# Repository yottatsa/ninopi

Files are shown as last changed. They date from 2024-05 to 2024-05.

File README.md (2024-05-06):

# ninopi

NinoTNC to Raspberry Pi integration board
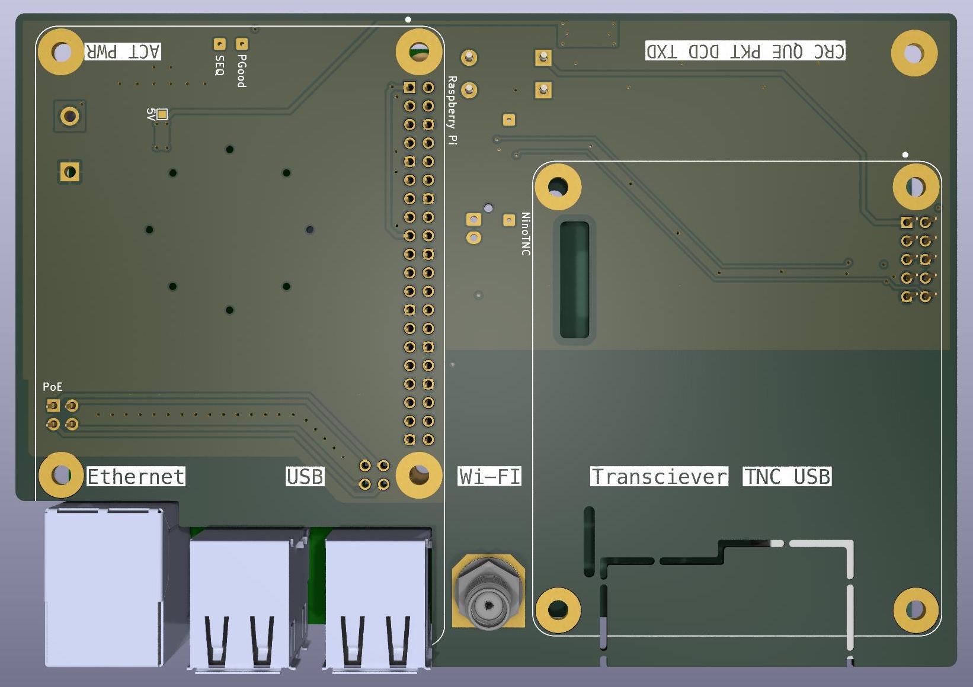
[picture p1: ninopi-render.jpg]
Card


[NinoTNC](https://tarpn.net/t/nino-tnc/nino-tnc.html) is 300-9600 baud multi-mode packet radio KISS TNC by [Nino Carrillo](https://github.com/ninocarrillo). This board bypassed provided USB-serial interface and uses rpi internal one.

This board also provides with [Recon 12V DC-DC converter](https://www.recom-power.com/pdf/Innoline/RPM-6.0.pdf) to power the rig from the same power rail, RPi and PoE headers pass-thru, Wi-Fi antenna mount, and simple fan PWM controller.

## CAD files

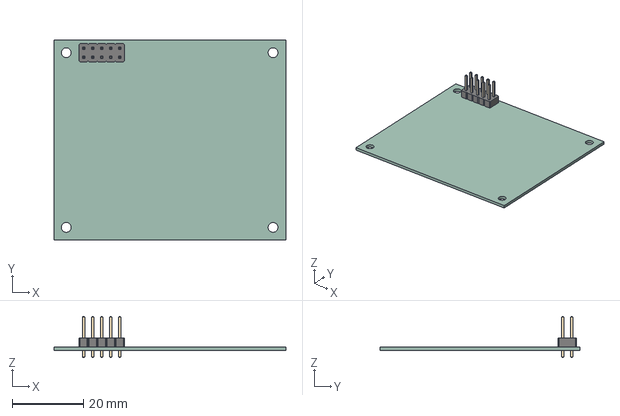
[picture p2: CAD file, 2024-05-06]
ninotnc.step
65.1 x 56.1 x 11.5 mm
_autosave-ninotnc PCB

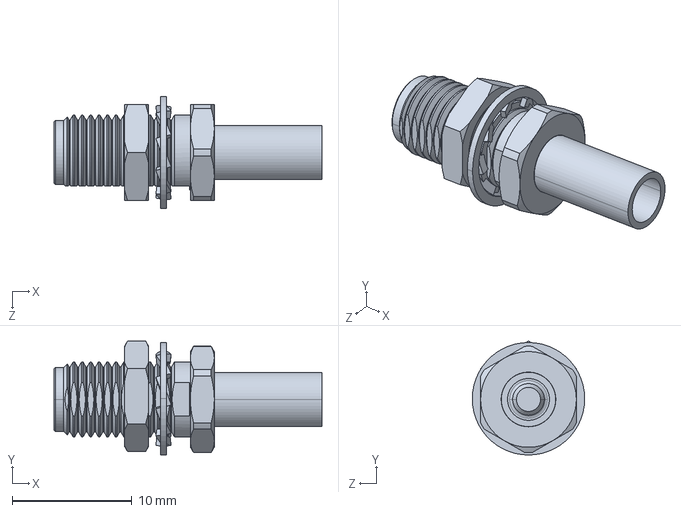
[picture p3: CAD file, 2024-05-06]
RASPBERRY_PI_3_MODEL_B_/7587.stp
22.4 x 9.52 x 9.40 mm

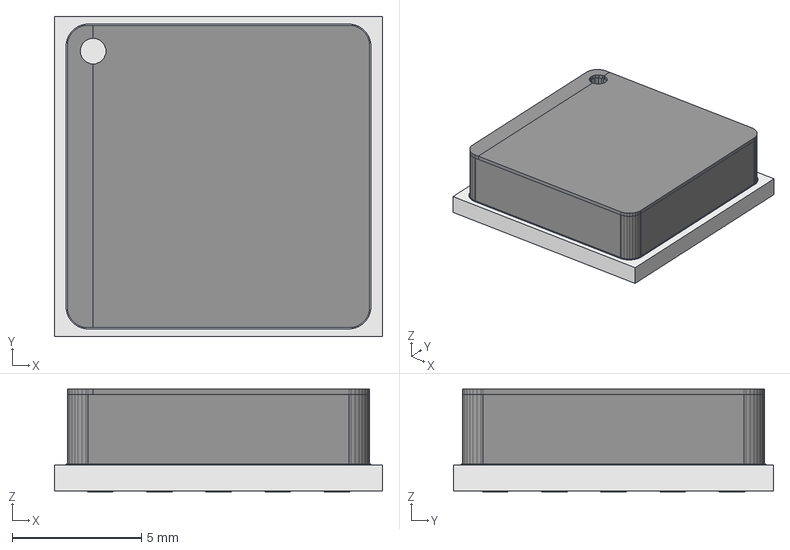
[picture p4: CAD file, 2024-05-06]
RPM60.stp
12.7 x 12.4 x 3.97 mm
Extruded.step x 2
Extruded-0.step x 2
Extruded-1.step x 2
Extruded-2.step x 2
Extruded-3.step x 2
Extruded-4.step x 2
Extruded-5.step003 x 4
Extruded-6.step003 x 4
RPM_RBB_PCB028
RPM_RBB_PCB029
RPM_RBB_PCB030
RPM_RBB_PCB031
RPM_RBB_PCB032
RPM_RBB_PCB033
RPM_RBB_PCB034
RPM_RBB_PCB035
RPM_RBB_PCB036
RPM_RBB_PCB037
RPM_RBB_PCB038
RPM_RBB_PCB039
RPM_RBB_PCB040
RPM_RBB_PCB041
RPM_RBB_PCB042
RPM_RBB_PCB043
RPM_RBB_PCB044
RPM_RBB_PCB045
RPM_RBB_PCB046
RPM_RBB_PCB047
RPM_RBB_PCB048
RPM_RBB_PCB049
RPM_RBB_PCB050
RPM_RBB_PCB051
RPM_RBB_PCB052
RPM_RBB_PCB053
RPM_RBB_PCB054
RPM_RBB_PCB
RPM_RBB_PCB001
RPM_RBB_PCB002
RPM_RBB_PCB003
RPM_RBB_PCB004
RPM_RBB_PCB005
RPM_RBB_PCB006
RPM_RBB_PCB007
RPM_RBB_PCB008
RPM_RBB_PCB009
RPM_RBB_PCB010
RPM_RBB_PCB011
RPM_RBB_PCB012
RPM_RBB_PCB013
RPM_RBB_PCB014
RPM_RBB_PCB015
RPM_RBB_PCB016
RPM_RBB_PCB017
RPM_RBB_PCB018
RPM_RBB_PCB019
RPM_RBB_PCB020
RPM_RBB_PCB021
RPM_RBB_PCB022
RPM_RBB_PCB023
RPM_RBB_PCB024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

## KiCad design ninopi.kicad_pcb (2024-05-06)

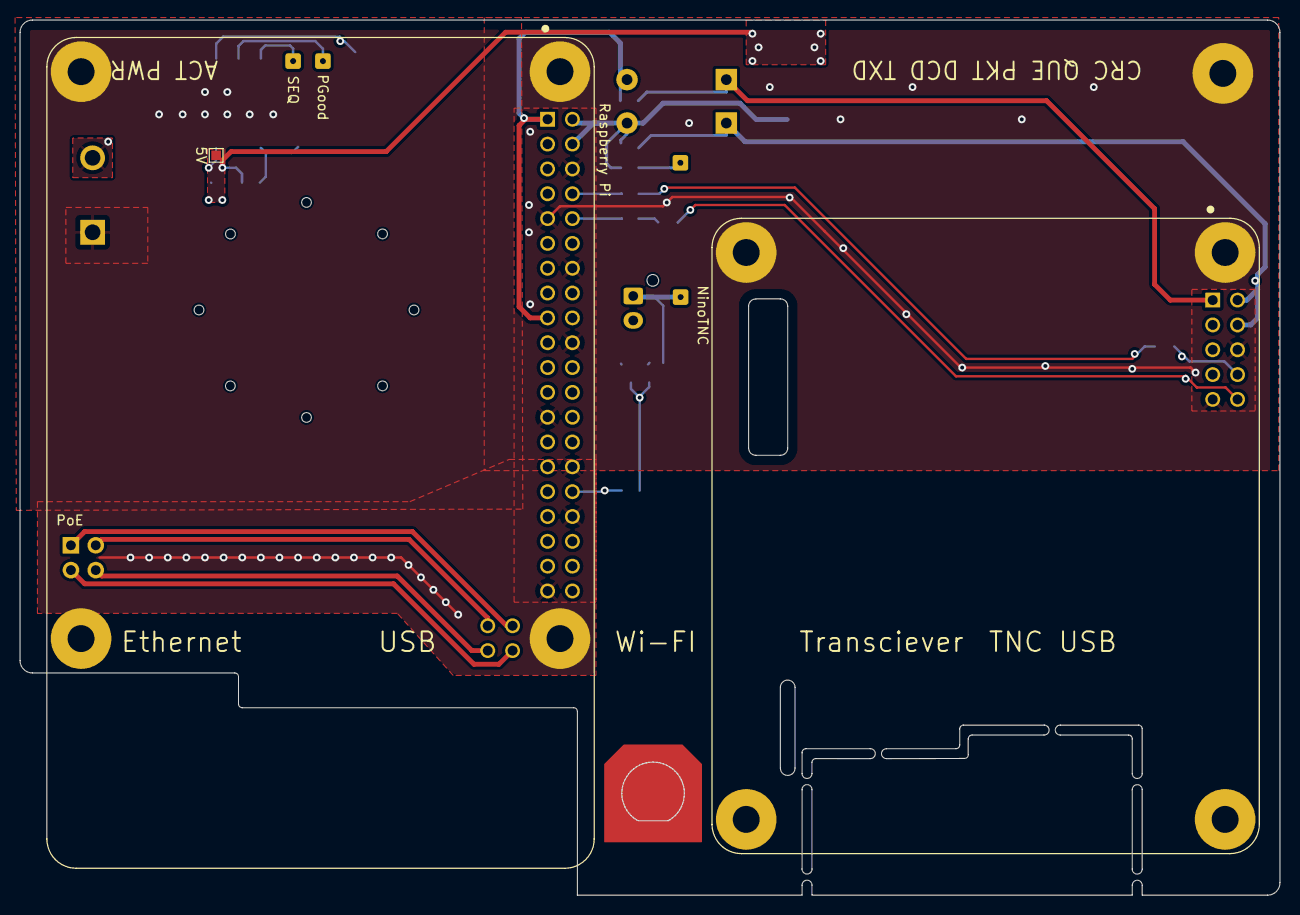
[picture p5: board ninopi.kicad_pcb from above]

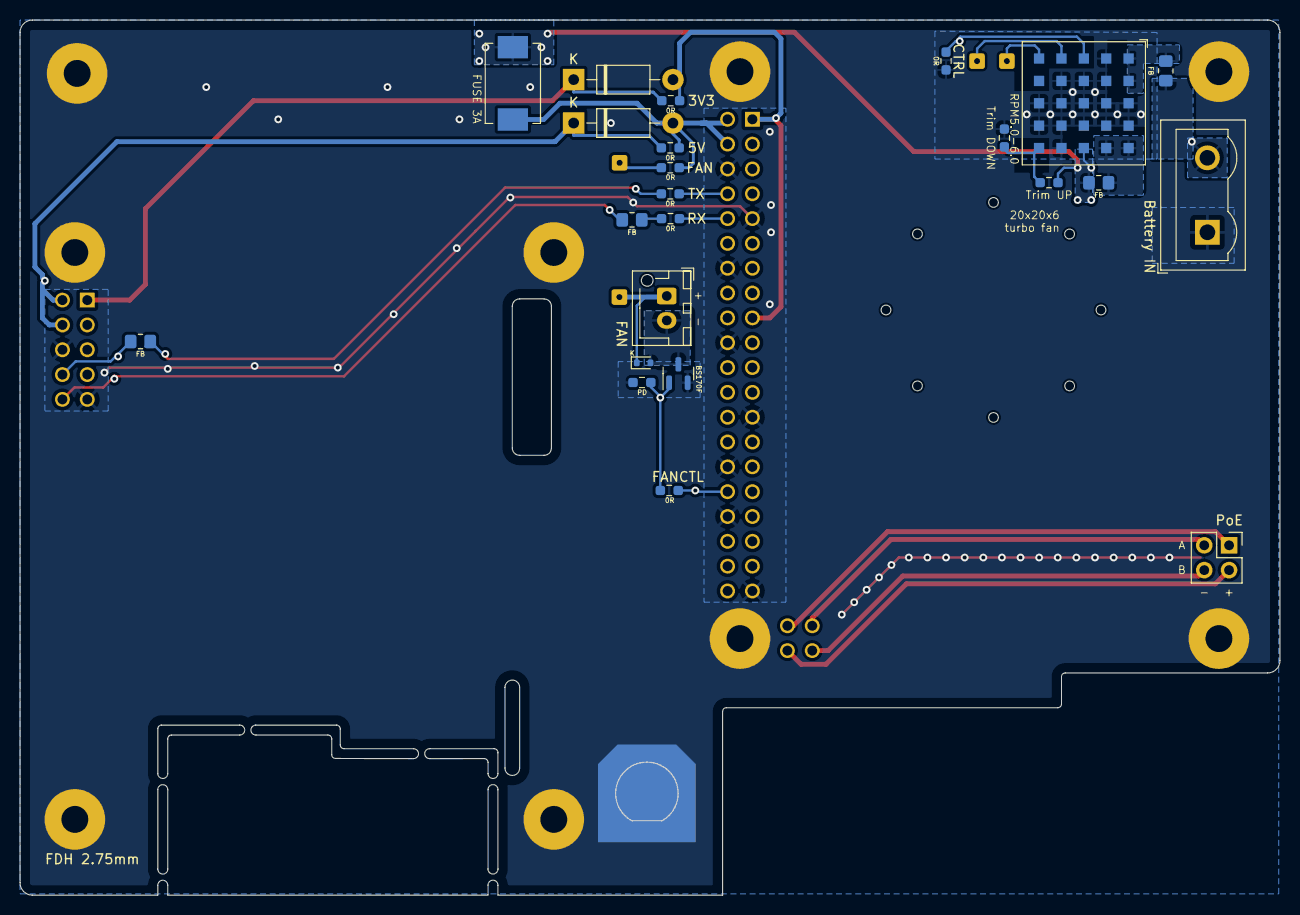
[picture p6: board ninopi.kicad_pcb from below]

Board: 2 copper layers, 128.9 x 89.5 mm, 29 parts (23 on the bottom side), 27 nets.

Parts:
5V: TestPoint_Pad_1.0x1.0mm
D1, D2: 1N4001; D_DO-41_SOD81_P10.16mm_Horizontal
D3: 1N4148WT; D_SOD-523
F2: FUSE 3A; Fuse_Bourns_MF-SM_7.98x5.44mm
FB1, FB2, FB3, FB4: FB; R_0805_2012Metric_Pad1.20x1.40mm_HandSolder
H1: Wi-Fi; SMARP
J1: Raspberry Pi; MODULE_RASPBERRY_PI_3_MODEL_B_
J2: NinoTNC; SMT_TARPN_NinoTNC
J3: PoE; PinSocket_2x02_P2.54mm_Vertical
J4: FAN; JST_XH_B2B-XH-AM_1x02_P2.50mm_Vertical
J5: Battery IN; TerminalBlock_Wuerth_691311400102_P7.62mm
Q1: BS170F; SOT-23
R1: TX; R_0603_1608Metric_Pad0.98x0.95mm_HandSolder
R2: RX; R_0603_1608Metric_Pad0.98x0.95mm_HandSolder
R3, R4, R5, R7: 0R; R_0603_1608Metric_Pad0.98x0.95mm_HandSolder
R6: PD; R_0603_1608Metric_Pad0.98x0.95mm_HandSolder
R8: CTRL; R_0603_1608Metric_Pad0.98x0.95mm_HandSolder
R9: Trim DOWN; R_0603_1608Metric_Pad0.98x0.95mm_HandSolder
R10: Trim UP; R_0603_1608Metric_Pad0.98x0.95mm_HandSolder
TP1: SEQ; SolderWire-0.1sqmm_1x01_D0.4mm_OD1mm
TP2: PGood; SolderWire-0.1sqmm_1x01_D0.4mm_OD1mm
U1: RPM5.0-6.0; Converter_DCDC_RECOM_RPMx.x-x.0

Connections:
3V3: D1.2 (A), J1.1 (3V3), J1.17 (3V3), R3.1
5V: D2.2 (A), F2.1, J1.2 (5V), J1.4 (5V), R4.2, R5.1
/5V.H1: FB2.1, U1.A5 (+VOUT), U1.B5 (+VOUT)
/FAN: D3.1 (K), J4.1, R5.2
/FANFET: D3.2 (A), J4.2, Q1.3 (D)
/TNC.3V3: D1.1 (K), J2.1 (3V3), R3.2
/TNC.5V: D2.1 (K), J2.2 (5V), J2.4 (5V), R4.1
/TR00: J1.44 (TR00), J3.1
/TR01: J1.43 (TR01), J3.2
/TR02: J1.42 (TR02), J3.3
/TR03: J1.41 (TR03), J3.4
FAN.PWM: J1.32 (PWM0/GPIO12), R7.1
GND: H1.GND, J1.6 (GND), J1.9 (GND), J1.14 (GND), J1.20 (GND), J1.25 (GND), J1.30 (GND), J1.34 (GND), J1.39 (GND), J2.6 (GND), J2.9 (GND), J5.1, Q1.2 (S), R6.1, R8.1, R9.1, U1.A3 (GND), U1.A4 (GND), U1.B1 (GND), U1.B2 (GND), U1.B3 (GND), U1.B4 (GND), U1.C2 (GND), U1.C3 (GND), U1.C4 (GND), U1.D2 (GND), U1.D3 (GND), U1.D4 (GND), U1.D5 (GND), U1.E3 (GND), U1.E4 (GND)
unnamed: FB1.2, U1.A1 (+VIN), U1.A2 (+VIN)
unnamed: FB3.2, R1.1
unnamed: FB4.2, R2.1
unnamed: FB4.1, J2.10 (RX)
unnamed: FB3.1, J2.8 (TX)
unnamed: Q1.1 (G), R6.2, R7.2
unnamed: R8.2, U1.C1 (CTRL)
unnamed: TP2.1, U1.D1 (PGood)
unnamed: TP1.1, U1.E1 (SEQ)
PWRTRIM: R9.2, R10.1, U1.E5 (Trim)
SENSE: F2.2, FB2.2, R10.2, U1.C5 (Sense)
UART0_RX: J1.10 (GPIO15/RXD), R2.2
UART0_TX: J1.8 (GPIO14/TXD), R1.2
VIN: FB1.1, J5.2
